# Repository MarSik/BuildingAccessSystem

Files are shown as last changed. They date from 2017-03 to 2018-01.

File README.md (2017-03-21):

# NFC entry system using TI Tiva C platform - with DESfire support

The aim is to use the [Tiva C Launchpad](http://www.ti.com/tool/ek-tm4c123gxl) together with [PN532 NFC interface boards](https://www.adafruit.com/products/364) to create a secure building access system.

This project is based on [Elmu's code for Teensy](http://www.codeproject.com/Articles/1096861/DIY-electronic-RFID-Door-Lock-with-Battery-Backup).

## Development environment

Please download [Energia](http://energia.nu), use the `Tools / Board / Board manager` menu item to download the Tiva/Stellaris support files and open the `DoorOpenerSketch.ino` file in it.

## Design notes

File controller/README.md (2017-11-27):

= Controller board for RFID door lock =

Install platformio.

Compile using:

```
pio run
```

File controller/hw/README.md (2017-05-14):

# Controller board

The PCB is not the best routed board ever, but I wanted a single copper layer board for a home made prototype to verify the functionality.

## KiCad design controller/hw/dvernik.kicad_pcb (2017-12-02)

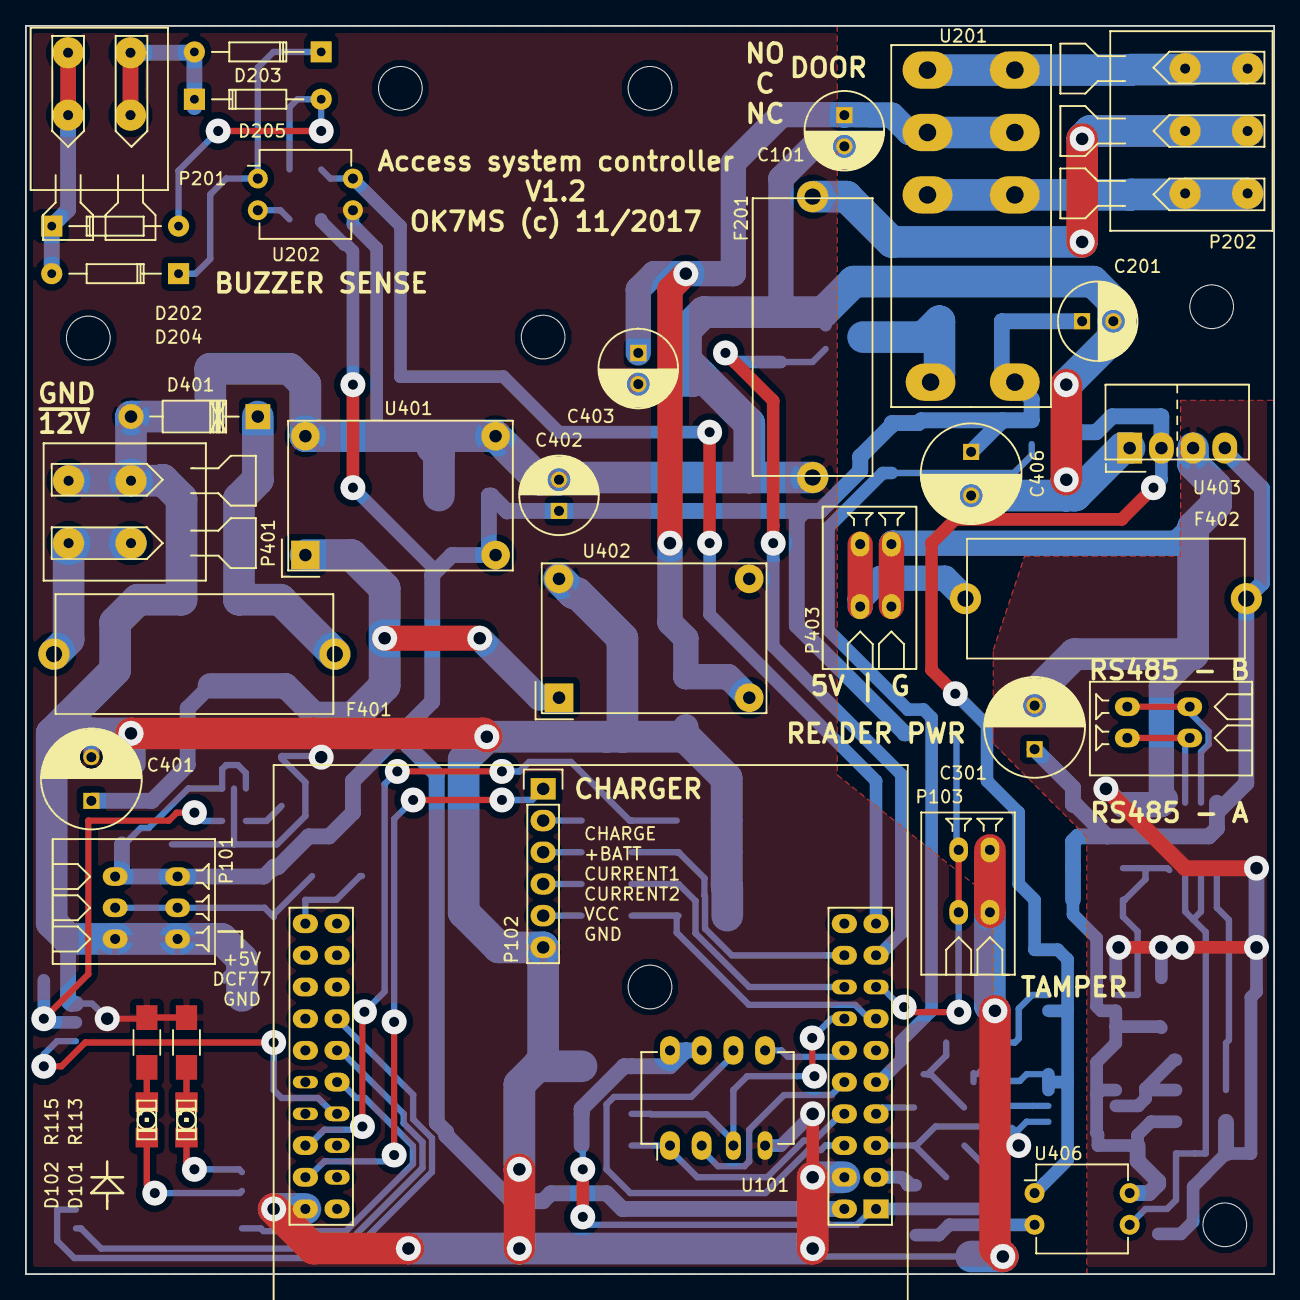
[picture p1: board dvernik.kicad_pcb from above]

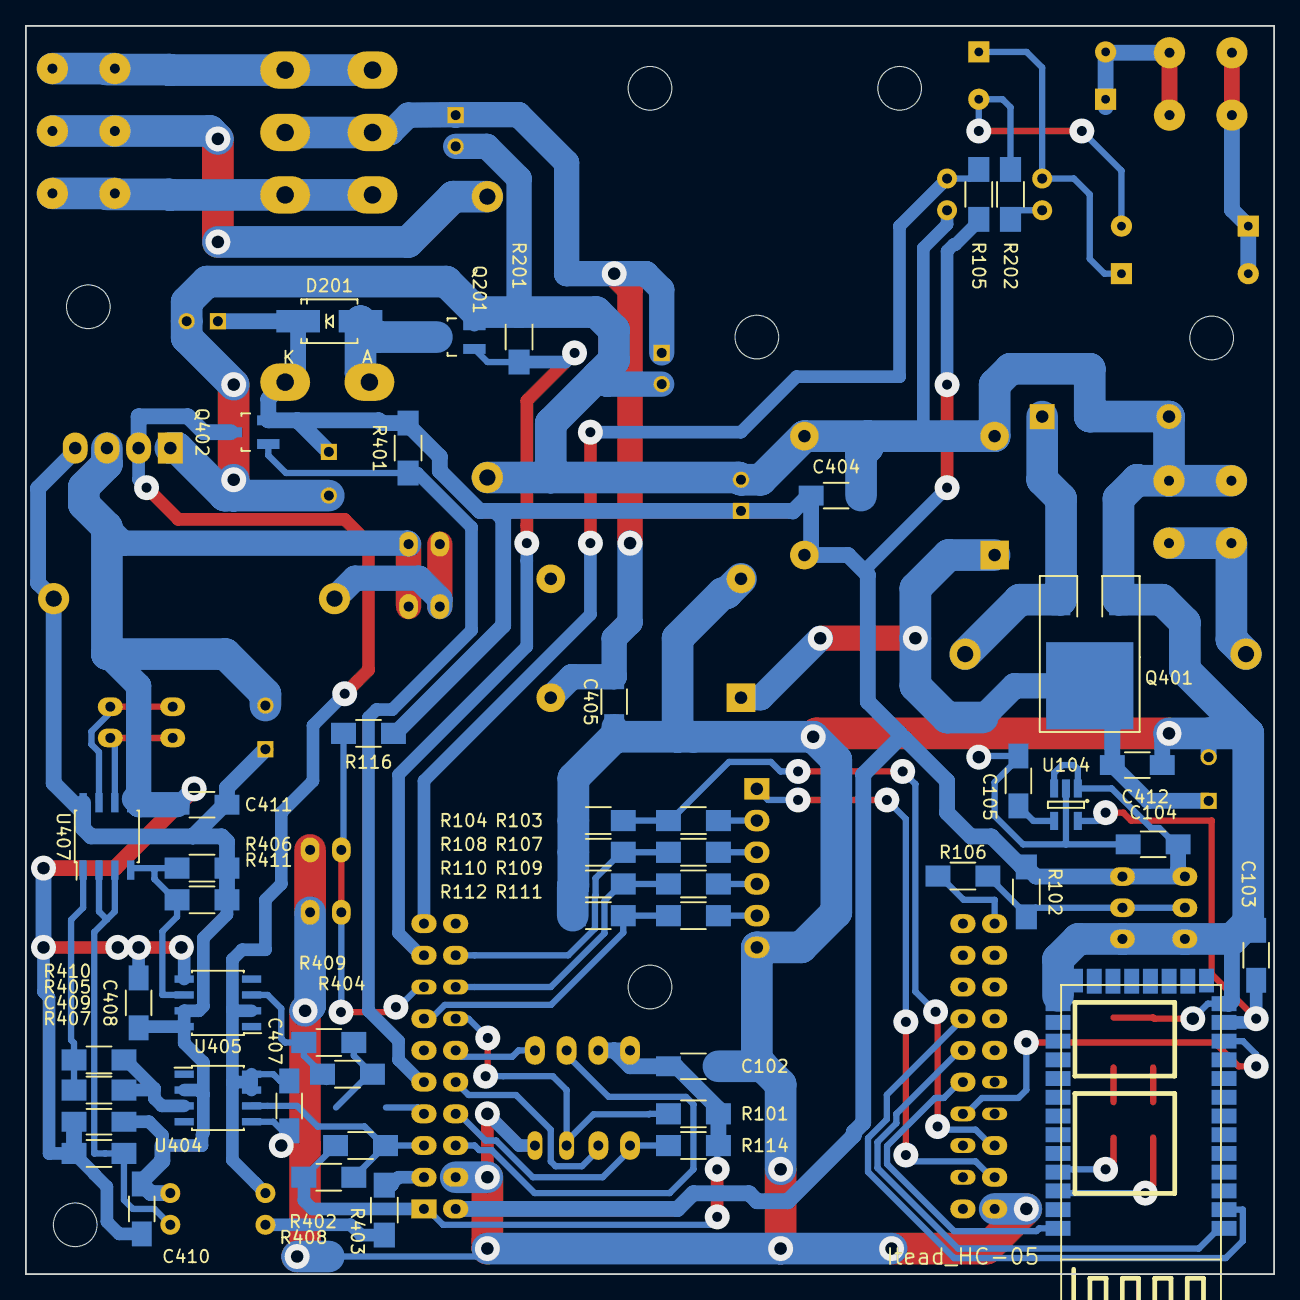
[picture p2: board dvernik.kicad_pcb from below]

Board: 2 copper layers, 100.0 x 100.0 mm, 83 parts (48 on the bottom side), 61 nets.

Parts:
C101, C201, C402, C403: Jamicon_220uF_16V_TKP; C_Radial_D6.3_L11.2_P2.5
C102, C104, C105, C404, C405, C412: C; C_1206_HandSoldering
C103, C407, C408, C409, C410, C411: 100n; C_1206_HandSoldering
C301, C401, C406: Jamicon_220uF_25V; C_Radial_D8_L11.5_P3.5
D101, D102: LED; LED-1206
D201: SK110; Diode-SMA_Handsoldering
D202, D203, D204, D205: SD103A; Diode_DO-35_SOD27_Horizontal_RM10
D401: BZX85C15; Diode_DO-41_SOD81_Horizontal_RM10
F201, F401, F402: FUSE; Fuse_5x20_Schurter-0031-8201
P101: WAGO233; Wire-3_Wago-233-P2.5mm
P102: CONN_01X06; Pin_Header_Straight_1x06
P103: CONN_01X02; Wire-2_Wago-233-P2.5mm
P201, P401: WAGO255; Wire-2_WAGO-255_P5mm_HandSoldering
P202: WAGO255; Wire-3_WAGO-255_P5mm_HandSoldering
P402, P403: Wago_233-502; Wire-2_Wago-233-P2.5mm
Q201: 2N7002K; SOT-23_HandSoldering
Q401: IRFU9024; DPAK_HandSoldering
Q402: IRLML6402; SOT-23_HandSoldering
R101, R102, R105, R114, R401, R407: 10k; R_1206_HandSoldering
R103, R107, R109, R111: 100k; R_1206_HandSoldering
R104, R108, R110, R112: 25k; R_1206_HandSoldering
R106: 0; R_1206_HandSoldering
R113, R115, R116, R201, R202, R403: R; R_1206_HandSoldering
R402, R404, R405, R406, R408, R409, R410, R411: 1k; R_1206_HandSoldering
U101: A25L40P; DIP-8_W300mil_LongPads
U102: EK-TM4C123GXL; TI-Launchpad_4-Ports_LargePads
U103: Itead_HC-05; RF_HC-0X_Itead_HandSoldering
U104: LP2992AIM5-3.3CT-ND; SOT-23-5_HandSoldering
U201: JQX-14FC22CS8-5.0; Relay_JQX-14FC_L5_HandSoldering
U202, U406: Cosmo_1010-817; DIP-4_W300mil
U401, U402: Mini-360; DcDc_MH_MINI_360
U403: ROE-0505S; DcDc_Roe_SIP-4
U404, U405: HCPL-0601-500E; SOIC-8_3.9x4.9mm_Pitch1.27mm
U407: SN75176BDR; SOIC-8_3.9x4.9mm_Pitch1.27mm

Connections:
+3V3: C102.1, R101.1, R114.1, R402.2, R408.2, U101.7, U101.8, U102.1.01
+5V: C104.1, C201.1, C402.1, C404.1, C406.1, D201.1, P101.1, Q402.2, R102.1, R105.1, R116.1, R401.2, U102.3.01, U104.1, U104.3, U201.8, U401.2
+5VA: C301.1, C408.1, C409.2, C410.2, C411.2, F402.2, R406.1, R411.1, U403.4, U404.2, U405.7, U405.8, U406.4, U407.8
+12V: C101.1, C403.1, C405.1, U201.3, U201.6, U402.2
+BATT: P102.2, R103.1
/BATT_SENSE: R103.2, R104.1, U102.2.03
/BT_AT_~COMM: U102.4.05, U103.34
/BUZZ1: R105.2, U102.1.10, U202.4
/CHARGE: P102.1, U102.2.02
/CHARGE_SENSE1: P102.4, R109.1
/CHARGE_SENSE2: P102.3, R107.1
/CPU_RX: R402.1, R408.1, U102.1.03, U404.6
/CPU_RX_BT: U102.4.06, U103.1
/CPU_TX_BT: U102.4.07, U103.2
/DCF77: R106.2, U102.2.10
/DOOR1: Q201.1, R201.1, U102.1.09
/Door1/BUZZER_COM: F201.1, P202.2
/Door1/BUZZER_IN1: D203.2, D205.1, P201.1
/Door1/BUZZER_IN2: D202.1, D204.2, P201.2
/Door1/BUZZER_NC: P202.1, U201.2, U201.7
/Door1/BUZZER_NO: P202.3, U201.4, U201.5
/Door1/RELAYGND: D201.2, Q201.3, U201.1
/MEM_CS: R114.2, U101.1, U102.3.04
/MEM_MISO: U101.2, U102.3.05
/MEM_MOSI: U101.5, U102.3.06
/MEM_SCK: U101.6, U102.3.03
/MEM_WP: R101.2, U101.3, U102.3.07
/Power/PFUSED: D401.1, F401.1, Q401.3
/Power/PIN: F401.2, P401.2
/ReaderIntf/485A: P402.1, U407.6
/ReaderIntf/485B: P402.2, U407.7
/ReaderIntf/CPU_TX5: R404.2, R409.2
/ReaderIntf/DCDCIN5V: C407.2, Q402.3, U403.2, U404.7, U404.8, U405.2, U406.1
/ReaderIntf/UNSAFE_RX: R405.1, R410.1, U407.1
/ReaderIntf/UNSAFE_TX: R406.2, R411.2, U405.6, U407.4
/ReaderIntf/~READER_ON: Q402.1, R401.1
/TAMPER: P103.1, R116.2, U102.1.08
/~BT_RESET: U102.4.04, U103.11
/~TX_EN: R403.2, U102.1.02
GND: C101.2, C102.2, C103.2, C104.2, C105.2, C201.2, C401.2, C402.2, C403.2, C404.2, C405.2, C406.2, C407.1, C412.2, D401.2, F201.2, P101.3, P102.6, P103.2, P401.1, Q201.2, Q401.1, R104.2, R108.2, R110.2, R112.2, R113.1, R115.1, R201.2, U101.4, U102.2.01, U102.3.02, U103.13, U103.21, U103.22, U104.2, U202.3, U401.3, U401.4, U402.3, U402.4, U403.1, U404.5
GNDA: C301.2, C408.2, C409.1, C410.1, C411.1, P403.2, R407.2, U403.3, U405.5, U407.5
unnamed: C103.1, U103.12, U104.5
unnamed: C105.1, U104.4
unnamed: C401.1, C412.1, Q401.4, U401.1, U402.1
unnamed: D101.1, R113.2
unnamed: D101.2, U103.31
unnamed: D102.1, R115.2
unnamed: D102.2, U103.32
unnamed: D202.2, D205.2, R202.2
unnamed: D203.1, D204.1, U202.1
unnamed: F402.1, P403.1
unnamed: P101.2, R102.2, R106.1
unnamed: R107.2, R108.1, U102.3.09
unnamed: R109.2, R110.1, U102.3.08
unnamed: R111.2, R112.1, U102.1.07
unnamed: R202.1, U202.2
unnamed: R403.1, U406.2
unnamed: R404.1, R409.1, U405.3
unnamed: R405.2, R410.2, U404.3
unnamed: R407.1, U406.3, U407.2, U407.3
VCC: P102.5, R111.1

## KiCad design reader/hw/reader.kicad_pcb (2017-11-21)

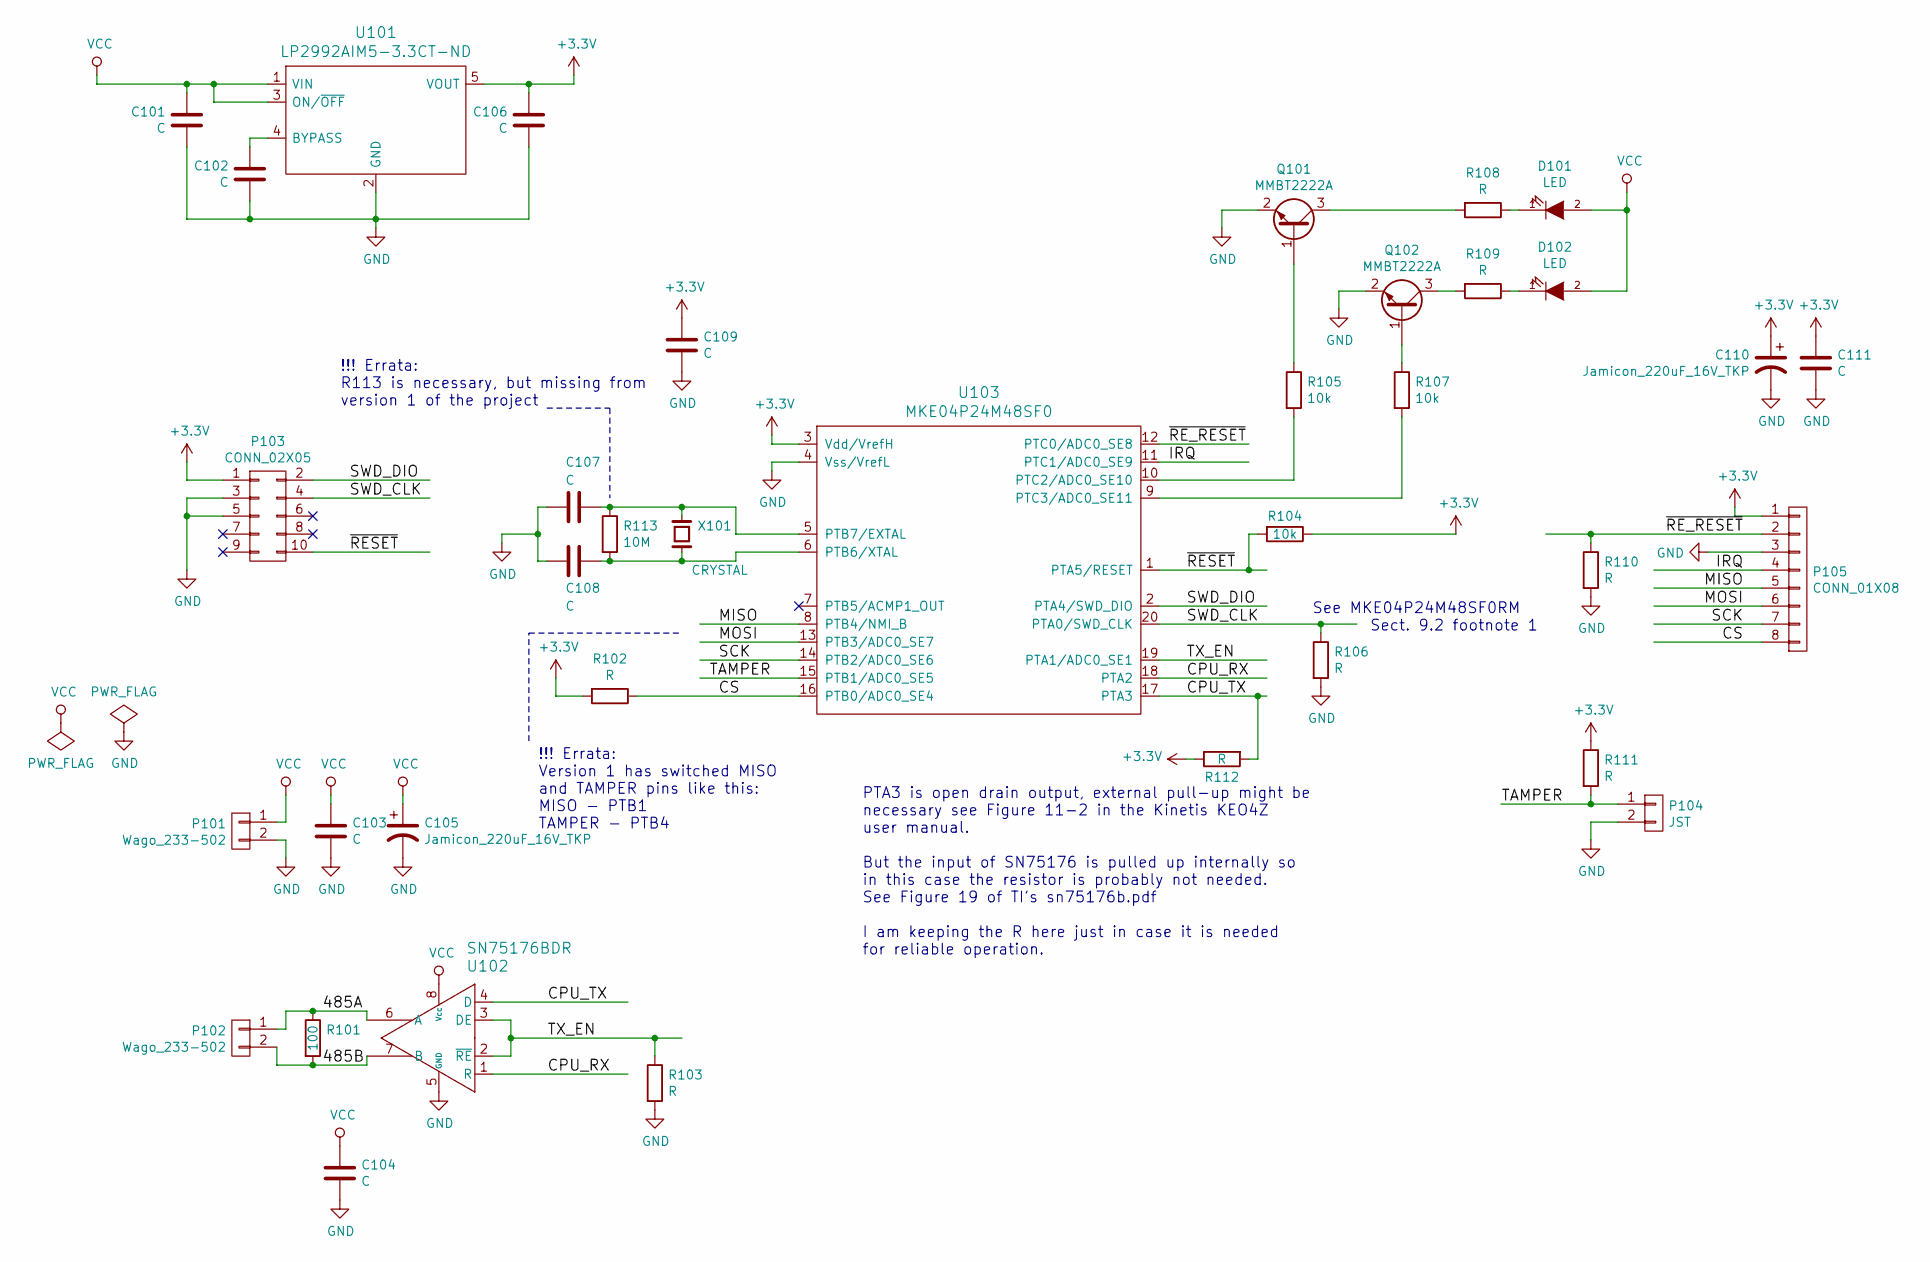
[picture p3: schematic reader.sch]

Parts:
C101, C102, C103, C104, C106, C107, C108, C109, C111: C; C_1206_HandSoldering
C105, C110: Jamicon_220uF_16V_TKP; C_Radial_D6.3_L11.2_P2.5
D101, D102: LED; LED-1206
P101, P102: Wago_233-502; Wire-2_Wago-233-P2.5mm
P103: CONN_02X05; Pin_Header_Straight_2x05
P104: JST; Connector_JST_PHR-2
P105: CONN_01X08; Pin_Header_Straight_1x08
Q101, Q102: MMBT2222A; SOT-23_HandSoldering
R101: 100; R_1206_HandSoldering
R102, R103, R106, R108, R109, R110, R111, R112: R; R_1206_HandSoldering
R104, R105, R107: 10k; R_1206_HandSoldering
R113: 10M; R_1206_HandSoldering
U101: LP2992AIM5-3.3CT-ND; SOT-23-5_HandSoldering
U102: SN75176BDR; SOIC-8_3.9x4.9mm_Pitch1.27mm
U103: MKE04P24M48SF0; SOIC-20_7.5x12.8mm_Pitch1.27mm
X101: CRYSTAL; Crystal_HC49-U_Vertical

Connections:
+3V3: C106.1, C109.1, C110.1, C111.1, P103.1, P105.1, R102.2, R104.1, R111.1, R112.1, U101.5 (VOUT), U103.3 (Vdd/VrefH)
/485A: P102.1, R101.1, U102.6 (A)
/485B: P102.2, R101.2, U102.7 (B)
/CPU_RX: U102.1 (R), U103.18 (PTA2)
/CPU_TX: R112.2, U102.4 (D), U103.17 (PTA3)
/CS: P105.8, R102.1, U103.16 (PTB0/ADC0_SE4)
/IRQ: P105.4, U103.11 (PTC1/ADC0_SE9)
/MISO: P105.5, U103.8 (PTB4/NMI_B)
/MOSI: P105.6, U103.13 (PTB3/ADC0_SE7)
/SCK: P105.7, U103.14 (PTB2/ADC0_SE6)
/SWD_CLK: P103.4, R106.1, U103.20 (PTA0/SWD_CLK)
/SWD_DIO: P103.2, U103.2 (PTA4/SWD_DIO)
/TAMPER: P104.1, R111.2, U103.15 (PTB1/ADC0_SE5)
/TX_EN: R103.1, U102.2 (~RE), U102.3 (DE), U103.19 (PTA1/ADC0_SE1)
/~RESET: P103.10, R104.2, U103.1 (PTA5/RESET)
/~RE_RESET: P105.2, R110.1, U103.12 (PTC0/ADC0_SE8)
GND: C101.2, C102.2, C103.2, C104.2, C105.2, C106.2, C107.2, C108.2, C109.2, C110.2, C111.2, P101.2, P103.3, P103.5, P104.2, P105.3, Q101.2 (E), Q102.2 (E), R103.2, R106.2, R110.2, U101.2 (GND), U102.5 (GND), U103.4 (Vss/VrefL)
unnamed: C102.1, U101.4 (BYPASS)
unnamed: C107.1, R113.1, U103.5 (PTB7/EXTAL), X101.1
unnamed: C108.1, R113.2, U103.6 (PTB6/XTAL), X101.2
unnamed: D101.1 (K), R108.1
unnamed: D102.1 (K), R109.1
unnamed: Q101.1 (B), R105.1
unnamed: Q101.3 (C), R108.2
unnamed: Q102.1 (B), R107.1
unnamed: Q102.3 (C), R109.2
unnamed: R105.2, U103.10 (PTC2/ADC0_SE10)
unnamed: R107.2, U103.9 (PTC3/ADC0_SE11)
VCC: C101.1, C103.1, C104.1, C105.1, D101.2 (A), D102.2 (A), P101.1, U101.1 (VIN), U101.3 (ON/~OFF), U102.8 (Vcc)

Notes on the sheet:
See MKE04P24M48SF0RM Sect. 9.2 footnote 1
PTA3 is open drain output, external pull-up might be necessary see Figure 11-2 in the Kinetis KEO4Z user manual. But the input of SN75176 is pulled up internally so in this case the resistor is probably not needed. See Figure 19 of TI's sn75176b.pdf I am keeping the R here just in case it is needed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
!!! Errata: Version 1 has switched MISO and TAMPER pins like this: MISO - PTB1 TAMPER - PTB4
!!! Errata: R113 is necessary, but missing from version 1 of the project

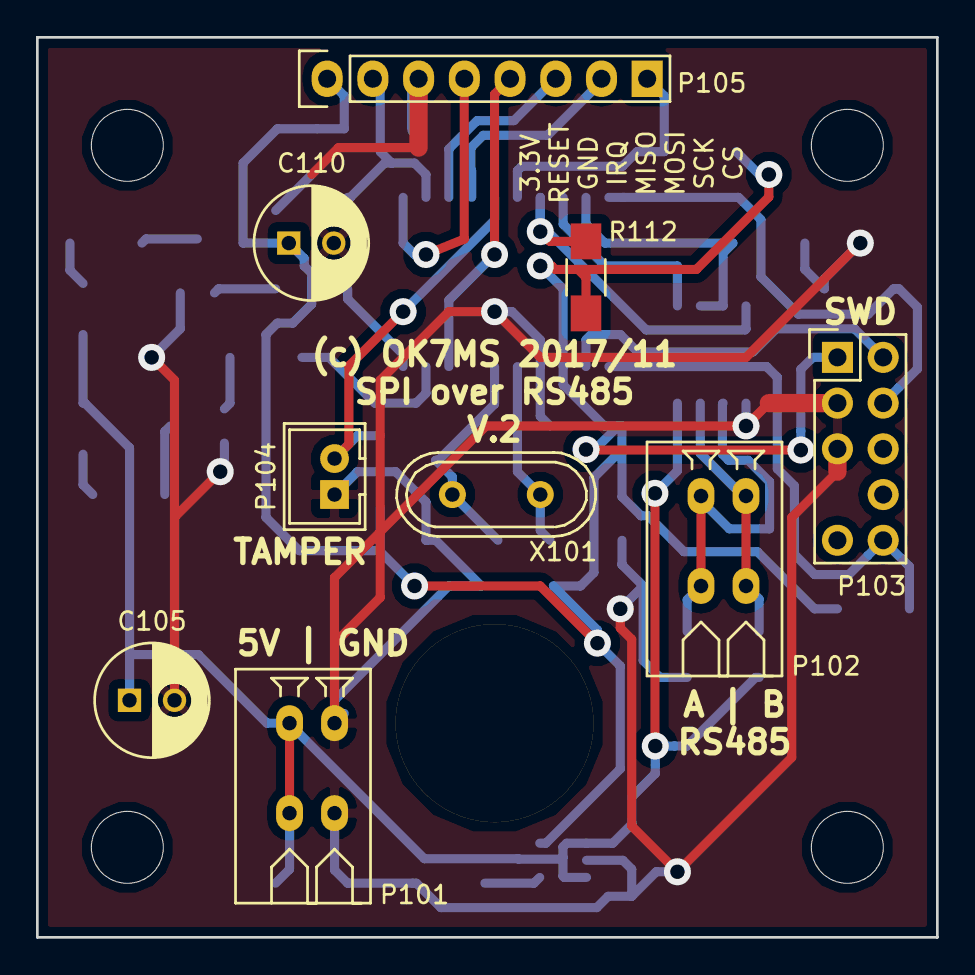
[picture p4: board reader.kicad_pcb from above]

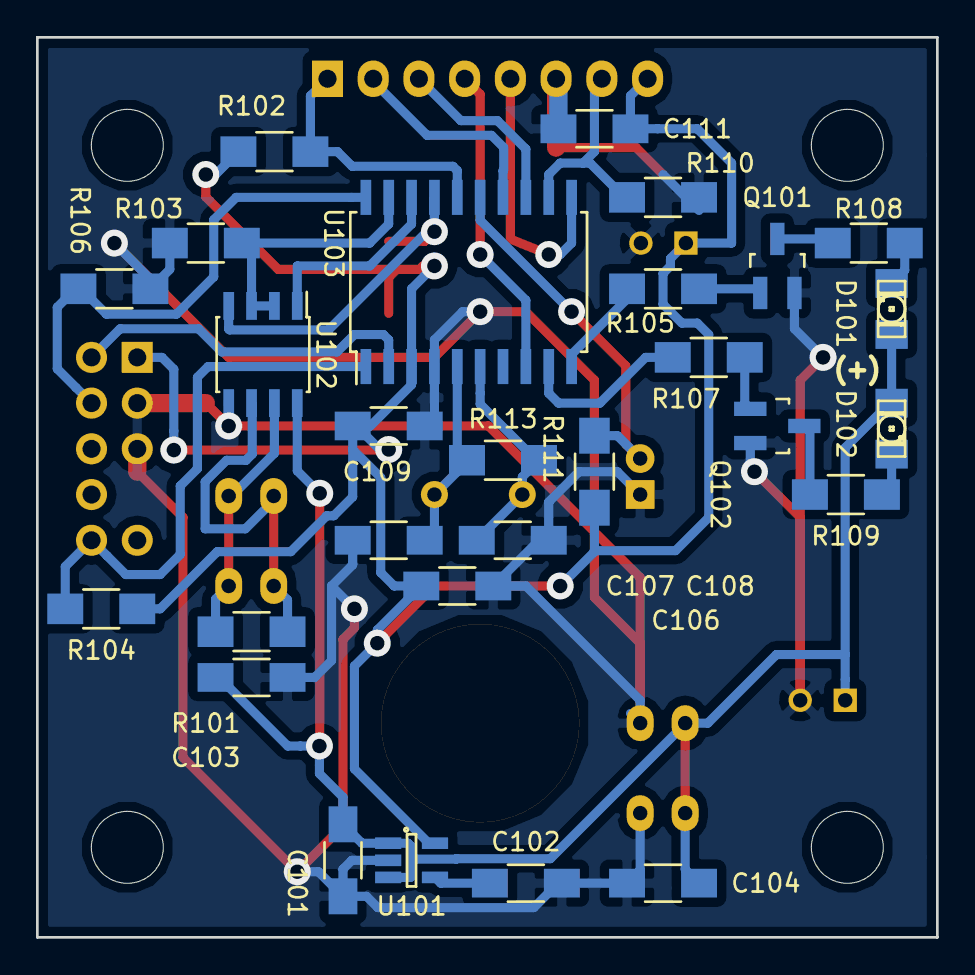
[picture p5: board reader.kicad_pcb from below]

Board: 2 copper layers, 50.0 x 50.0 mm, 37 parts (28 on the bottom side), 29 nets.

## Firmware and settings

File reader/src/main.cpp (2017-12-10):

#include "mke04z4.h"

/* !!! Check schematic errata
 * = V1 =
 * Real MISO pin is connected to PTB4, but the P105 header's MISO signal
 * is connected to PTB1.
 *
 * Workaround:
 * use TAMPER as MISO and MISO as TAMPER (needs external pull-up)
 *
 * = V2 =
 * TAMPER and MISO mixup sorted out. Software uses PTB4 as MISO.
 *
 */

/*
 * The goal is to convert rs485 stream to SPI commands for
 * NFC card reader + allow additional commands:
 *  - LED1 on/off
 *  - LED2 on/off
 *  - RESET reader
 *
 * It would be best if the protocol was device independent.
 * SPI buffer size at least 8B
 *
 * TODO I will probably use the following protocol:
 * > START
 * > 1B high level command [LED, SPI, RESET]
 * > X B SPI data
 * > END frame break
 * - delay 500us
 * < START
 * < 1B status (0x00 = OK, 0xFF = ERROR)
 * < X B SPI response
 * < END frame break
 *
 * control byte in data will be escaped by prefixing the byte with ESC and then
 * transmitting the real byte XOR 0x20
 *
 * START = {
 * END = }
 * ESC = \
 */

// UART status
typedef struct {
    uint8_t buffer[64];
    uint8_t cur = 0;
    uint8_t size = 0;
} Buffer_t;

volatile Buffer_t TxBuffer;
volatile Buffer_t RxBuffer;

static volatile uint8_t spiSent = 0;
static volatile uint8_t spiReceived = 0;

static const uint8_t FRAME_MARKER_START = '{';
static const uint8_t FRAME_MARKER_ESC = 0x7E;
static const uint8_t FRAME_MARKER_ESC_XOR = 0x20;
static const uint8_t FRAME_MARKER_END = '}';

volatile enum {
    FRAME_IDLE, // Line idle, both RX and TX can be started
    FRAME_ACTIVE, // Line is receiving frame
    FRAME_ESC, // Next received byte is escaped
    FRAME_DONE, // Whole frame received
    FRAME_TX, // Line is ready to send or sending data
    FRAME_TX_IDLE, // Line has no data to send, but frame was not terminated
    FRAME_TX_ENDING // Frame terminator is the last symbol in the queue
} FrameState = FRAME_IDLE;

static const uint32_t PTC0 = 1 << 16; // ~RESET for card reader
static const uint32_t PTC2 = 1 << 18; // Led 1
static const uint32_t PTC3 = 1 << 19; // Led 2
static const uint32_t PTA1 = 1 <<  1; // TXEN for RS485 driver
static const uint32_t PTB0 = 1 <<  8; // CS

void _sendNextByte();
bool serialSend();
void serialQueueEnd();
void serialQueueBuffer(volatile Buffer_t* buffer);
void serialQueue(uint8_t byte);

extern "C" {

// Create big endian version of the number
// See: https://community.nxp.com/thread/350150?commentID=498593#comment
#define BIG_SHORT_WORD(x) (unsigned short)((x << 8) | (x >> 8))

void LowLevelInit(void) {
    // Disable NMI
    SIM->SOPT &= ~SIM_SOPT_NMIE_MASK;

    // Reconfigure watchdog
    __disable_irq();
    WDOG->CNT = 0x20C5; // unlock configuration
    WDOG->CNT = 0x28D9;
    WDOG->TOVAL = BIG_SHORT_WORD(30000); // 30s reset
    WDOG->WIN = 0;
    WDOG->CS2 = WDOG_CS2_CLK_MASK // setting 1-kHz clock source
                | WDOG_CS2_FLG_MASK; // clear WDOG interrupt flag
    WDOG->CS1 = 0 // WDOG_CS1_EN_MASK // enable counter running
                | WDOG_CS1_DBG_MASK
                | WDOG_CS1_STOP_MASK
                | WDOG_CS1_WAIT_MASK; // enable watchdog in all modes
    __enable_irq();

    SIM->SCGC |= SIM_SCGC_SWD_MASK
            | SIM_SCGC_FLASH_MASK
            ;

    OSC->CR |= OSC_CR_OSCEN_MASK
            | OSC_CR_RANGE_MASK
            | OSC_CR_OSCOS_MASK
            | OSC_CR_OSCSTEN_MASK; // range high, crystal on, auto gain

    while ((OSC->CR & OSC_CR_OSCINIT_MASK) == 0); // waiting until oscillator is ready

    ICS->C1 = (0b011 << ICS_C1_RDIV_SHIFT); // ref divide by 256 -> 40 Mhz main clock
    ICS->C2 = 0;

    //ICS->C1 = (0b000 << ICS_C1_RDIV_SHIFT | ICS_C1_IREFS_MASK); // ref divide by 1, internal

}

void SystemInit(void) { 
    SIM->SCGC |= SIM_SCGC_UART0_MASK
            | SIM_SCGC_SPI0_MASK
            ;
}

void primeSend() {
    SysTick->VAL = 0;
    SysTick->CTRL = SysTick_CTRL_TICKINT_Msk
                    | SysTick_CTRL_ENABLE_Msk
                    | SysTick_CTRL_CLKSOURCE_Msk;
}

int main(void) {
    GPIOA->PIDR |= PTC2 | PTC3 | PTA1 | PTC0 | PTB0; // disable input
    GPIOA->PDDR |= PTC2 | PTC3 | PTA1 | PTC0 | PTB0; // set as output

    FGPIOA->PSOR = PTC2 | PTC3 | PTC0 | PTB0; // set output to 1
    FGPIOA->PCOR = PTA1; // clear output to 0

    // UART on PTA2 / PTA3
    SIM->PINSEL |= SIM_PINSEL_UART0PS_MASK;

    // Configure clock dividers (1 / 2 / 1) to set Bus clock = System clock / 2 -> 20 Mhz
    SIM->CLKDIV = SIM_CLKDIV_OUTDIV2_MASK;

    // UART prescaler
    UART0->BDH = 0;
    UART0->BDL = 11; // Bus clock 20Mhz, 115200 baud

    // TX and RX enable, incl. interrupts
    UART0->C2 |= UART_C2_TE_MASK
                 | UART_C2_RE_MASK
                 | UART_C2_RIE_MASK;

    NVIC_EnableIRQ(UART0_IRQn);

    // Configure SPI0
    // Errata: remove tamper resistor and connect PTB4 with PTB1 in rev.1 of the board
    SPI0->C1 = SPI_C1_SPE_MASK
               | SPI_C1_SPIE_MASK
               | SPI_C1_MSTR_MASK
               | SPI_C1_CPHA_MASK
               | SPI_C1_CPOL_MASK;
    SPI0->C2 = 0;
    SPI0->BR = SPI_BR_SPPR_MASK | 0b0010; // prescalers 8 and 8 -> cca 300kHz SPI clock

    NVIC_EnableIRQ(SPI0_IRQn);

    // Configure SysTick reload value
    // (X-1 see http://infocenter.arm.com/help/index.jsp?topic=/com.arm.doc.dui0662b/BGBEEJHC.html)
    SysTick->LOAD = 5000 - 1; // 125us (5000 cycles at 40Mhz)
    SysTick->CTRL = 0;

    GPIOA->PTOR = PTC2 | PTC3; // toggle outputs off

    // Main echo loop
    while (1) {
        /* Reset watchdog clock
        __disable_irq();
        WDOG->CNT = 0x02A6;
        WDOG->CNT = 0x80B4;
        __enable_irq(); */

        if (FrameState == FRAME_DONE) {
            // Process received data - echo it back
            FrameState = FRAME_IDLE;

            // Set pins
            if (RxBuffer.size == 2
                && RxBuffer.buffer[0] == 0x01) {
                if (RxBuffer.buffer[1] & 0b001) {
                    FGPIOA->PSOR = PTB0;
                }

                if (RxBuffer.buffer[1] & 0b010) {
                    FGPIOA->PSOR = PTC2;
                }

                if (RxBuffer.buffer[1] & 0b100) {
                    FGPIOA->PSOR = PTC3;
                }

                if (RxBuffer.buffer[1] & 0b1000) {
                    FGPIOA->PSOR = PTC0;
                }

                serialQueue(0x00); // OK marker
                serialQueueEnd();
                primeSend();
                continue;
            }

            // Clear pins
            if (RxBuffer.size == 2
                && RxBuffer.buffer[0] == 0x02) {
                if (RxBuffer.buffer[1] & 0b001) {
                    FGPIOA->PCOR = PTB0;
                }

                if (RxBuffer.buffer[1] & 0b010) {
                    FGPIOA->PCOR = PTC2;
                }

                if (RxBuffer.buffer[1] & 0b100) {
                    FGPIOA->PCOR = PTC3;
                }

                if (RxBuffer.buffer[1] & 0b1000) {
                    FGPIOA->PCOR = PTC0;
                }

                serialQueue(0x00); // OK marker
                serialQueueEnd();
                primeSend();
                continue;
            }


            if (RxBuffer.size > 1
                && RxBuffer.buffer[0] == 0x00) {
                RxBuffer.cur++; // Skip command byte
                serialQueue(0x00); // OK marker

                // Pass first data byte to SPI and enable interrupts
                spiSent = 1;
                spiReceived = 0;
                while (!(SPI0->S & SPI_S_SPTEF_MASK)) {
                    // Wait for the send buffer to be empty
                    // See section: 30.3.5
                }
                SPI0->D = RxBuffer.buffer[RxBuffer.cur++];
                if (RxBuffer.cur < RxBuffer.size) {
                    SPI0->C1 |= SPI_C1_SPTIE_MASK;
                }
                continue;
            }

            // SPI configuration byte
            if (RxBuffer.size == 2
                && RxBuffer.buffer[0] == 0xE0) {

                SPI0->C1 = RxBuffer.buffer[1]
                           | SPI_C1_SPIE_MASK
                           | SPI_C1_MSTR_MASK;

                serialQueue(0x00); // OK marker
                serialQueueEnd();
                primeSend();
                continue;
            }

            if (RxBuffer.size == 2
                && RxBuffer.buffer[0] == 0xE2) {

                SPI0->C2 = RxBuffer.buffer[1];

                serialQueue(0x00); // OK marker
                serialQueueEnd();
                primeSend();
                continue;
            }

            // SPI baud rate configuration byte
            if (RxBuffer.size == 2
                && RxBuffer.buffer[0] == 0xE1) {

                SPI0->BR = RxBuffer.buffer[1] & 0b01111111;

                serialQueue(0x00); // OK marker
                serialQueueEnd();
                primeSend();
                continue;
            }

            // UART speed
            if (RxBuffer.size == 2
                && RxBuffer.buffer[0] == 0xE3) {

                if (RxBuffer.buffer[1] > 0) {
                    serialQueue(0x00); // OK marker
                } else {
                    serialQueue(0xFF);
                }
                serialQueueEnd();
                primeSend();

                if (RxBuffer.buffer[1] == 0) {
                    continue;
                }

                // finish transmitting before changing speed
                while (FrameState != FRAME_IDLE)
                    ;

                UART0->BDL = RxBuffer.buffer[1];
                continue;
            }

            // About
            if (RxBuffer.size == 1
                && RxBuffer.buffer[0] == 0xFF) {

                serialQueue(0x00); // OK marker

                // Announce itself
                serialQueue('O');
                serialQueue('K');
                serialQueueEnd();
                primeSend();
                continue;
            }

            // Echo data back (DEBUG)
            serialQueue(0xff); // error marker
            serialQueueBuffer(&RxBuffer);
            serialQueueEnd();
            primeSend();
        }

        __WFI();
    }
}

void SPI0_IRQHandler(void) {
    uint8_t status = SPI0->S;

    if (status & SPI_S_SPTEF_MASK) {
        if (RxBuffer.cur < RxBuffer.size) {
            SPI0->D = RxBuffer.buffer[RxBuffer.cur++];
            spiSent++;
            if (RxBuffer.cur == RxBuffer.size) {
                // Last byte queued; disable TX interrupt
                SPI0->C1 &= ~SPI_C1_SPTIE_MASK;
            }
        }
    }

    if (status & SPI_S_SPRF_MASK) {
        const uint8_t data = SPI0->D;
        serialQueue(data);
        spiReceived++;
        if (spiReceived == spiSent && RxBuffer.cur == RxBuffer.size) {
            // Last byte processed, trigger uart
            serialQueueEnd();
            primeSend();
        }
    }
}

void UART0_IRQHandler(void) {
    // Character received
    uint8_t s1 = UART0->S1;
    if (s1 & UART_S1_RDRF_MASK) {
        uint8_t data = UART0->D;

        switch (FrameState) {
            case FRAME_IDLE:
                // Start frame is used for resynchronization
                if (data == FRAME_MARKER_START) {
                    FrameState = FRAME_ACTIVE;
                    RxBuffer.cur = RxBuffer.size = 0;
                }
                break;

            case FRAME_TX:
            case FRAME_TX_IDLE:
            case FRAME_TX_ENDING:
            case FRAME_DONE:
                break;

            case FRAME_ESC:
                data ^= FRAME_MARKER_ESC_XOR;
                RxBuffer.buffer[RxBuffer.size++] = data;
                FrameState = FRAME_ACTIVE;
                break;

            case FRAME_ACTIVE:
                switch (data) {
                    case FRAME_MARKER_START:
                        // Start frame is used for resynchronization
                        // and cannot appear in data
                        FrameState = FRAME_ACTIVE;
                        RxBuffer.cur = RxBuffer.size = 0;
                        break;
                    case FRAME_MARKER_ESC:
                        FrameState = FRAME_ESC;
                        break;
                    case FRAME_MARKER_END:
                        FrameState = FRAME_DONE;
                        break;
                    default:
                        RxBuffer.buffer[RxBuffer.size++] = data;
                        break;
                }
                break;
        }
    }

    // TX buffer is ready to receive new byte
    if (s1 & UART_S1_TDRE_MASK
            && (FrameState == FRAME_TX || FrameState == FRAME_TX_ENDING)) {
        _sendNextByte();
    }

    // Tx buffer transmitted
    if (s1 & UART_S1_TC_MASK
            && TxBuffer.cur == TxBuffer.size
            && FrameState == FRAME_TX_ENDING) {
        FrameState = FRAME_IDLE;

        // Disable TX interrupts
        UART0->C2 &= ~(UART_C2_TIE_MASK | UART_C2_TCIE_MASK);

        // Disable driver TX direction
        FGPIOA->PCOR = PTA1;
    }
}

void SysTick_Handler(void) {
    SysTick->CTRL = 0;
    serialSend();
}

void NMI_Handler(void) {
    // Disable NMI
    SIM->SOPT &= ~SIM_SOPT_NMIE_MASK;
}

}

void _sendNextByte() {
    // Enable driver TX direction
    FGPIOA->PSOR = PTA1;

    if (TxBuffer.cur < TxBuffer.size) {
        UART0->D = TxBuffer.buffer[TxBuffer.cur++];
    } else if (FrameState != FRAME_TX_ENDING) {
        FrameState = FRAME_TX_IDLE;
    }
}

void serialQueueBuffer(volatile Buffer_t *buffer) {
    for (uint8_t idx = 0; idx < RxBuffer.size; idx++) {
        serialQueue(buffer->buffer[idx]);
    }
}

void serialQueue(uint8_t byte) {
    if (FrameState == FRAME_IDLE || FrameState == FRAME_TX_IDLE || FrameState == FRAME_TX_ENDING) {
        if (FrameState != FRAME_TX_ENDING) {
            TxBuffer.size = TxBuffer.cur = 0;
        }

        if (FrameState == FRAME_IDLE || FrameState == FRAME_TX_ENDING) {
            TxBuffer.buffer[TxBuffer.size++] = FRAME_MARKER_START;
        }

        FrameState = FRAME_TX;
    }

    if (FrameState == FRAME_TX) {
        if (byte == FRAME_MARKER_START || byte == FRAME_MARKER_ESC || byte == FRAME_MARKER_END) {
            byte ^= FRAME_MARKER_ESC_XOR;
            TxBuffer.buffer[TxBuffer.size++] = FRAME_MARKER_ESC;
        }
        TxBuffer.buffer[TxBuffer.size++] = byte;
    }
}

bool serialSend() {
    if (FrameState != FRAME_TX && FrameState != FRAME_TX_ENDING) {
        return false;
    }

    // Always read UART_S1 before writing to UART_D to allow
    // data to be transmitted.
    if (UART0->S1 & UART_S1_TDRE_MASK) {
        _sendNextByte();

        // Enable TX interrupts
        UART0->C2 |= UART_C2_TIE_MASK | UART_C2_TCIE_MASK;
    }

    return true;
}

void serialQueueEnd() {
    if (FrameState == FRAME_TX || FrameState == FRAME_TX_IDLE) {
        TxBuffer.buffer[TxBuffer.size++] = FRAME_MARKER_END;
        FrameState = FRAME_TX_ENDING;
    }
}

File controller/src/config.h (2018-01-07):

#ifndef PROJECT_CONFIG_H
#define PROJECT_CONFIG_H

// This password will be required when entering via Terminal
// If you define an empty string here, no password is requested.
// If any unauthorized person may access the dooropener hardware phyically you should provide a password!
#define PASSWORD  ""
// The interval of inactivity in minutes after which the password must be entered again (automatic log-off)
#define PASSWORD_TIMEOUT  5

// The tick counter starts at zero when the CPU is reset.
// This interval is added to the 64 bit tick count to get a value that does not start at zero,
// because gu64_LastPasswd is initialized with 0 and must always be in the past.
#define PASSWORD_OFFSET_MS   (2 * PASSWORD_TIMEOUT * 60 * 1000)

// This Arduino / Teensy pin is connected to the relay that opens the door 1
#define DOOR_PIN       PA_6
// Sensing whether someone is pushing the door open button
#define BUZZ_SENSE     PA_7

// Tamper detection pin
#define TAMPER         PA_5

// This Arduino / Teensy pin is connected to the transistor that charges the battery
#define CHARGE_PIN       PB_2
#define CHARGE_BATTERY_ADC A3
#define CHARGE_CURR1_ADC A1
#define CHARGE_CURR2_ADC A0
#define CHARGE_VCC_ADC A10

// Bluetooth pins
#define BT_RESET PC_4
#define BT_AT PC_5 // AT log.1, communication log.0
#define BT_SERIAL 3

// SPI flash memory
#define MEM_CS PD_1
#define MEM_SPI 3
#define MEM_WP PE_1 // WP log.0

// Reader
// Make sure the TX pin can provide at least 8mA
#define READER_SERIAL 1
#define READER_TX PB_5 // TX active log.0
#define READER_ON PE_4 // ON log.0

// This Arduino / Teensy pin is connected to the reader RSTPDN pin (reset the reader)
// When a communication error with the reader is detected the board is reset automatically.
#define RESET_PIN         READER_ON


// This Arduino / Teensy pin is connected to the green LED in a two color LED.
// The green LED flashes fast while no card is present and flashes 1 second when opening the door.
#define LED_GREEN_PIN    GREEN_LED

// This Arduino / Teensy pin is connected to the red LED in a two color LED.
// The red LED flashes slowly when a communication error occurred with the reader chip and when an unauthorized person tries to open the door.
// It flashes fast when a power failure has been detected. (Charging battery failed)
#define LED_RED_PIN      RED_LED

// This Arduino / Teensy pin is connected to the voltage divider that measures the 13,6V battery voltage
#define VOLTAGE_MEASURE_PIN  CHARGE_BATTERY_ADC

// Use 12 bit resolution for the analog input (ADC)
// The Teensy 3.x boards have a 12 bit ADC.
#define ANALOG_RESOLUTION  12

// The analog reference voltage (float) of the CPU (analogReference(DEFAULT) --> 3.3V, analogReference(INTERNAL1V2) --> 1.2V)
#define ANALOG_REFERENCE   1.2

// This factor (float) is used to calculate the battery voltage.
// If the external voltage divider is 220 kOhm / 15 kOhm the factor is theoretically 15.66666 == (220 + 15) / 15.
// You must fine tune this value until the battery voltage is displayed correctly when you hit Enter in the Terminal.
// Therefor you must unplug the 220V power suppply and measure the real voltage at the battery.
#define VOLTAGE_FACTOR   15.9

// The interval in milliseconds that the relay is powered which opens the door
#define OPEN_INTERVAL   1000

// This is the interval that the RF field is switched off to save battery.
// The shorter this interval, the more power is consumed by the reader.
// The longer  this interval, the longer the user has to wait until the door opens.
// The recommended interval is 1000 ms.
#define RF_OFF_INTERVAL  500

#ifndef LED_BUILTIN
#define LED_BUILTIN BLUE_LED
#endif // LED_BUILTIN

// DCF77 receiver
#define DCF77_PIN PA_2

#endif

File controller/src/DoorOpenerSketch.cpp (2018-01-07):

/**************************************************************************

  @author   Elmü
  DIY electronic RFID Door Lock with Battery Backup (2016)

  Check for a new version of this code on
  http://www.codeproject.com/Articles/1096861/DIY-electronic-RFID-Door-Lock-with-Battery-Backup

**************************************************************************/

#include "config.h"

// ######################################################################################

#include <Arduino.h>
#undef min
#undef max

#include <vector.h>


#include "SPI.h"
#include "DCF77.h"
#include "Time.h"
#include "MFRC522Ultralight.h"
#include "MFRC522Intf.h"
#include "Utils.h"
#include "Secrets.h"
#include "cardmanager.h"
#include "states.h"
#include "countdown.h"
#include "keyboard.h"
#include "hal.h"

DCF77 DCF = DCF77(DCF77_PIN, DCF77_PIN);

MFRC522IntfSpiOver485 mfrcIntf(Serial1, READER_TX);
MFRC522Ultralight<MFRC522IntfSpiOver485> mfrc522(mfrcIntf, READER_ON);  // Create MFRC522 instance
CardManager<MFRC522IntfSpiOver485> cardManager(mfrc522);

// global variables
uint64_t   gu64_LastID     = 0;     // The last card UID that has been read by the RFID reader
bool       gb_InitSuccess  = false; // true if the reader has been initialized successfully

void _prepareHighCurrentODOutputGPIO(const uint8_t arduinoPort);

// returns the voltage at the given pin in Volt multiplied with 10
uint32_t MeasureVoltage(byte u8_Pin)
{
    const uint32_t maxValue = (1 << ANALOG_RESOLUTION) -1;  // == 4095 for 12 bit resolution

    float value = 10.0 * analogRead(u8_Pin);
    return (uint32_t)((value * ANALOG_REFERENCE * VOLTAGE_FACTOR) / maxValue);
}

// returns true if the battery voltage is OK (between 13 and 14 Volt)
// The perfect voltage for a 12V lead-acid battery is 13,6V.
// This voltage guarantees the longest possible life of the battery.
// This function must be called very frequently because at this voltage the battery has a high impedance
// and the voltage rises very quickly when charging with 200mA
bool CheckBattery()
{
    uint32_t u32_Volt = MeasureVoltage(VOLTAGE_MEASURE_PIN);
    if (u32_Volt > 136)
        Utils::WritePin(CHARGE_PIN, LOW); // Stop charging

    if (u32_Volt < 134)
        Utils::WritePin(CHARGE_PIN, HIGH); // Start charging

    return (u32_Volt >= 130 && u32_Volt < 140);
}

// Reads the card in the RF field.
// ATTENTION: If no card is present, this function returns false. This is not an error.
bool ReadCard(uint64_t* uid)
{
  // Enable field
  if (!mfrc522.PCD_AntennaOn()) {
      return false;
  }
  //delay(100);

  // Look for new cards
  if ( ! mfrc522.PICC_IsNewCardPresent()) {
      RootLogger.println(INFO, "No new card present.");
      return false;
  }

  RootLogger.println(INFO, "Card detected...");

  // Select one of the cards
  StatusCode result = mfrc522.PICC_Select(&mfrc522.uid);
  if (result == STATUS_INTERNAL_ERROR || result == STATUS_ERROR || result == STATUS_TIMEOUT) {
      RootLogger.print(DEBUG, "Select failed: ");
      RootLogger.println(DEBUG, result, HEX);
      gb_InitSuccess = false;
      return false;
  }
  if (result != STATUS_OK) {
      return false;
  }

  // Convert the card id to binary
  *uid = 0;
  for (uint8_t idx = 0; idx < mfrc522.uid.size; idx++) {
    *uid <<= 8;
    *uid += mfrc522.uid.uidByte[idx];
  }

  // Dump debug info about the card; PICC_HaltA() is automatically called
  mfrc522.PICC_DumpDetailsToSerial(&(mfrc522.uid), Serial);
  return true;
}

// If everything works correctly, the green LED will flash shortly (20 ms).
// If the LED does not flash permanently this means that there is a severe error.
// Additionally the LED will flash long (for 1 second) when the door is opened.
// -----------------------------------------------------------------------------
// The red LED shows a communication error with the reader (flash very slow),
// or someone not authorized trying to open the door (flash for 1 second)
// or on power failure the red LED flashes shortly.
/* void FlashLED(eLED e_LED, int s32_Interval)
{
    SetLED(e_LED);
    LongDelay(s32_Interval);
    SetLED(LED_OFF);
} */

// Reset the reader chip and initialize, set gb_InitSuccess = true on success
// If b_ShowError == true -> flash the red LED very slwoly
void InitReader(bool b_ShowError)
{
    if (b_ShowError)
    {
        SetLED(LED_RED);
        Utils::Print("Communication Error -> Reset reader\r\n");
    }

    do // pseudo loop (just used for aborting with break;)
    {
        gb_InitSuccess = false;

        Serial.println("Initializing reader...");
        if (!mfrc522.PCD_Init()) return;		// Init MFRC522
        Serial.println("Getting reader info..");
        mfrc522.PCD_DumpVersionToSerial(Serial);	// Show details of PCD - MFRC522 Card Reader details
        Serial.println("Setting gain");
        mfrc522.PCD_SetAntennaGain(PCD_RxGain::RxGain_avg);
        if (!mfrc522.PCD_WriteRegister(PCD_Register::RxThresholdReg, 0x22)) return;
        Serial.println(F("Reader initialized."));

        // XXX Set the max number of retry attempts to read from a card.

        gb_InitSuccess = true;
    }
    while (false);
}

// ================================================================================

// Store key to EEPROM
void SetKey(const char* key)
{
    if (strlen(key) != 32) {
        Utils::Print("Wrong key length! The key must be 32 HEX chars long (16B)", LF);
        return;
    }

    byte newKey[16] = {0,};
    for (uint8_t idx = 0; idx < 32; idx++) {
        byte val;
        switch (key[idx]) {
            case '0':
            case '1':
            case '2':
            case '3':
            case '4':
            case '5':
            case '6':
            case '7':
            case '8':
            case '9':
                val = key[idx] - '0';
                break;
            case 'a':
            case 'b':
            case 'c':
            case 'd':
            case 'e':
            case 'f':
                val = 0xa + key[idx] - 'a';
                break;

            case 'A':
            case 'B':
            case 'C':
            case 'D':
            case 'E':
            case 'F':
                val = 0xa + key[idx] - 'A';
                break;

            default:
                Serial.print("Invalid hex character ");
                Serial.write(key[idx]);
                Serial.print(" at index ");
                Serial.write(idx);
                Serial.print("!\r\n");
                return;
        }

        if (idx % 2 == 0) { // high nibble first
            val <<= 4;
        }

        newKey[idx >> 1] |= val;
    }

    setApplicationKey(newKey);
}

volatile bool _buzzerActivated = false;

void handleBuzzer(void) {
    const int val = digitalRead(BUZZ_SENSE);
    _buzzerActivated = val == LOW;

    if (val == LOW) {
        digitalWrite(DOOR_PIN, HIGH);
    } else {
        digitalWrite(DOOR_PIN, LOW);
    }
}
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

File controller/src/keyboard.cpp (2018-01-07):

#include <Arduino.h>
#undef min
#undef max

#include <logging.h>
#include <MFRC522Common.h>
#include <Time.h>
#include "DCF77.h"

#include <vector.h>
#include <cstring.h>
#include "config.h"
#include "keyboard.h"
#include "Utils.h"
#include "states.h"
#include "bluetooth.h"

etl::string<128> gs8_CommandBuffer;  // Stores commands typed by the user via Terminal and the password
uint64_t   gu64_LastPasswd = 0;     // Timestamp when the user has enetered the password successfully

// Temporary prototypes
extern DCF77 DCF;
void SetKey(const char* key);
void digitalClockDisplay();
uint32_t MeasureVoltage(byte u8_Pin);

void InitializeKB() {
    gs8_CommandBuffer[0] = 0;
}

void OnCommandReceived(bool b_PasswordValid);

// Checks if the user has typed anything in the Terminal program and stores it in gs8_CommandBuffer
// Execute the command when Enter has been hit.
// returns true if any key has been pressed since the last call to this function.
bool ReadKeyboardInput()
{
    uint64_t u64_Now = Utils::GetMillis64() + PASSWORD_OFFSET_MS;

    bool b_KeyPress = false;
    while (SerialClass::Available())
    {
        b_KeyPress = true;
        // Check if the password must be entered
        bool b_PasswordValid = PASSWORD[0] == 0 || (u64_Now - gu64_LastPasswd) < (PASSWORD_TIMEOUT * 60 * 1000);

        byte u8_Char = SerialClass::Read();
        char s8_Echo[] = { (char)u8_Char, 0 };

        if (u8_Char == '\r' || u8_Char == '\n')
        {
            OnCommandReceived(b_PasswordValid);
            gs8_CommandBuffer.clear();
            Utils::Print("\r\n> ");
            continue;
        }

        if (u8_Char == 8) // backslash
        {
            if (!gs8_CommandBuffer.empty())
            {
                gs8_CommandBuffer.pop_back();
                Utils::Print(s8_Echo); // Terminal Echo
            }
            continue;
        }

        // Ignore all other control characters and characters that the terminal will not print correctly (e.g. umlauts)
        if (u8_Char < 32 || u8_Char > 126)
            continue;

        // Terminal Echo
        if (b_PasswordValid) Utils::Print(s8_Echo);
        else                 Utils::Print("*"); // don't display the password chars in the Terminal

        if (gs8_CommandBuffer.available() == 0)
        {
            Utils::Print("ERROR: Command too long\r\n");
            gs8_CommandBuffer.clear();
        }

        gs8_CommandBuffer.push_back(u8_Char);
    }
    return b_KeyPress;
}

// Parse the parameter behind "ADD", "DEL" and "DEBUG" commands and trim spaces
bool ParseParameter(char* s8_Command, char** ps8_Parameter, int minLength, int maxLength)
{
    int P=0;
    if (s8_Command[P++] != ' ')
    {
        // The first char after the command must be a space
        Utils::Print("Invalid command\r\n");
        return false;
    }

    // Trim spaces at the begin
    while (s8_Command[P] == ' ')
    {
        P++;
    }

    char* s8_Param = s8_Command + P;
    int   s32_Len  = strlen(s8_Param);

    // Trim spaces at the end
    while (s32_Len > 0 && s8_Param[s32_Len-1] == ' ')
    {
        s32_Len--;
        s8_Param[s32_Len] = 0;
    }

    if (s32_Len > maxLength)
    {
        Utils::Print("Parameter too long.\r\n");
        return false;
    }
    if (s32_Len < minLength)
    {
        Utils::Print("Parameter too short.\r\n");
        return false;
    }

    *ps8_Parameter = s8_Param;
    return true;
}
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

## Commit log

2017-04-04 [WIP] Use hight speed uart instead of spi
2017-04-23 More source hacks to compile for RC522 (SPI and does not work yetpio run)
2017-05-05 Fix compilation with card manager
    [DoorOpenerSketch.cpp, Secrets.cpp, cardmanager.h]
2017-05-08 WIP Use UART mode with better error handling
    [DoorOpenerSketch.cpp]
2017-05-08 Fixed UART mode - it now reads Ultraliht C properly
    But the first RC522 init sequence still fails and triggers
    RC522 restart. All seems to work after that.
    Error handling of post-select communication needs to be
    improved too.
    [DoorOpenerSketch.cpp]
2017-05-08 Add logging abstraction to avoid direct usage of Serial from libraries
    [DoorOpenerSketch.cpp]
2017-05-14 v1 of controller PCB, mostly single layer with a few jumpers
    [door.sch, dvernik.kicad_pcb, dvernik.sch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]
2017-05-15 Fix drill sizes, silkscreen and add name and version markings
    [dvernik.kicad_pcb]
2017-05-20 Add reader board
    [dvernik.kicad_pcb, reader.kicad_pcb, reader.sch]
2017-05-22 Slight improvements to hardware design
    [door.sch, dvernik.kicad_pcb, dvernik.sch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]
2017-05-25 Restructure files and small updates
    [door.sch, dvernik.kicad_pcb, dvernik.sch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]
2017-06-07 Fix silkscreen
    [dvernik.kicad_pcb, reader.kicad_pcb]
2017-06-10 Fix voltage for SPI flash, short under one capacitor
    [dvernik.kicad_pcb, dvernik.sch, power.sch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]
2017-06-10 Save latest changes to sch
    [dvernik.sch, power.sch, reader_intf.sch]
2017-06-15 Fix door pin definition
    [DoorOpenerSketch.cpp]
2017-06-15 Pin definitions according to the built board
2017-11-14 Play with LEDs
2017-11-18 New KiCAD lib references, crystal feedback R, basic uart impl
    [reader.sch]
2017-11-20 SPI bridge implementation
2017-11-21 Fix MISO/TAMPER issue, fix watchdog, fix corruption when SPI cmd + 1 byte data
    [reader.kicad_pcb, reader.sch]
2017-11-23 Align reader & controller to use SPI over RS485
2017-11-26 Compilability using embc lm4f, fixes to TX_EN switching
    [door.sch, dvernik.sch, power.sch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]
2017-11-27 Fix serious hw bug (5V level on 3.3V tolerant RX/TX on ctrl board)
    [door.sch, dvernik.kicad_pcb, dvernik.sch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]
2017-11-28 Fix controller issues with 3.3V CPU interfacing 5V logic
    [dvernik.kicad_pcb, reader_intf.sch]
2017-12-02 Use Arduino library prepared by FindArduino
2017-12-02 WIP Still working in 3.3 - 5V interface issues
    [dvernik.kicad_pcb, dvernik.sch, power.sch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]
2017-12-04 Disable NMI in reader board
2017-12-05 WDT timer counter is big-endian!
2017-12-05 WIP updates to controller - open drain, style, debugging, pin defs
2017-12-08 Fixes controller writeBye escaping and allows remote SPI configuration
    [DoorOpenerSketch.cpp, main.cpp]
2017-12-10 Fix response delay timing (5ms -> 125us) and other time constants a bit
    [DoorOpenerSketch.cpp, main.cpp]
2017-12-13 WIP fill in missing bits to card manager and personalization procedures
    [DoorOpenerSketch.cpp, cardmanager.h]
2017-12-13 Fix CRC deserialization when reading card data
    [cardmanager.h]
2017-12-13 Flash red led when card is rejected
2017-12-14 Separate pin assignments to config.h
2018-01-02 schematic improvements (door state pin for controller, fixes)
    [dvernik.sch, power.sch, reader.sch]
2018-01-06 Add missing stack protector symbols
    [bluetooth.cpp]
2018-01-07 Fix BT serial bug (sleev vs. delay), use etl::string for command buffer and reenable DCF
    [DoorOpenerSketch.cpp, bluetooth.cpp, keyboard.cpp]
